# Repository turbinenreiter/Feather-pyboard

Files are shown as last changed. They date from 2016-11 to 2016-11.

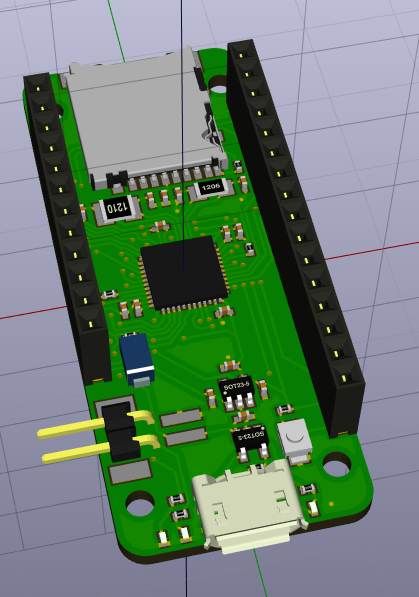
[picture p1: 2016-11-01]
Feather-Pyboard.png

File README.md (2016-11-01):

# Feather-pyboard

A STM32F411 development board compatible with the Feather form factor and designed to run MicroPython.

*NOTE: The desing is as of yet untested.*

This design heavily leans on [Adafruit Feather M0 Adalogger](https://github.com/adafruit/Adafruit-Feather-M0-Adalogger-PCB), [MicroPython pyboard](https://github.com/micropython/pyboard) and [Espruino Pico](https://github.com/espruino/EspruinoBoard/tree/master/Pico).

[Creative Commons Attribution, Share-Alike license](https://creativecommons.org/licenses/by/4.0)

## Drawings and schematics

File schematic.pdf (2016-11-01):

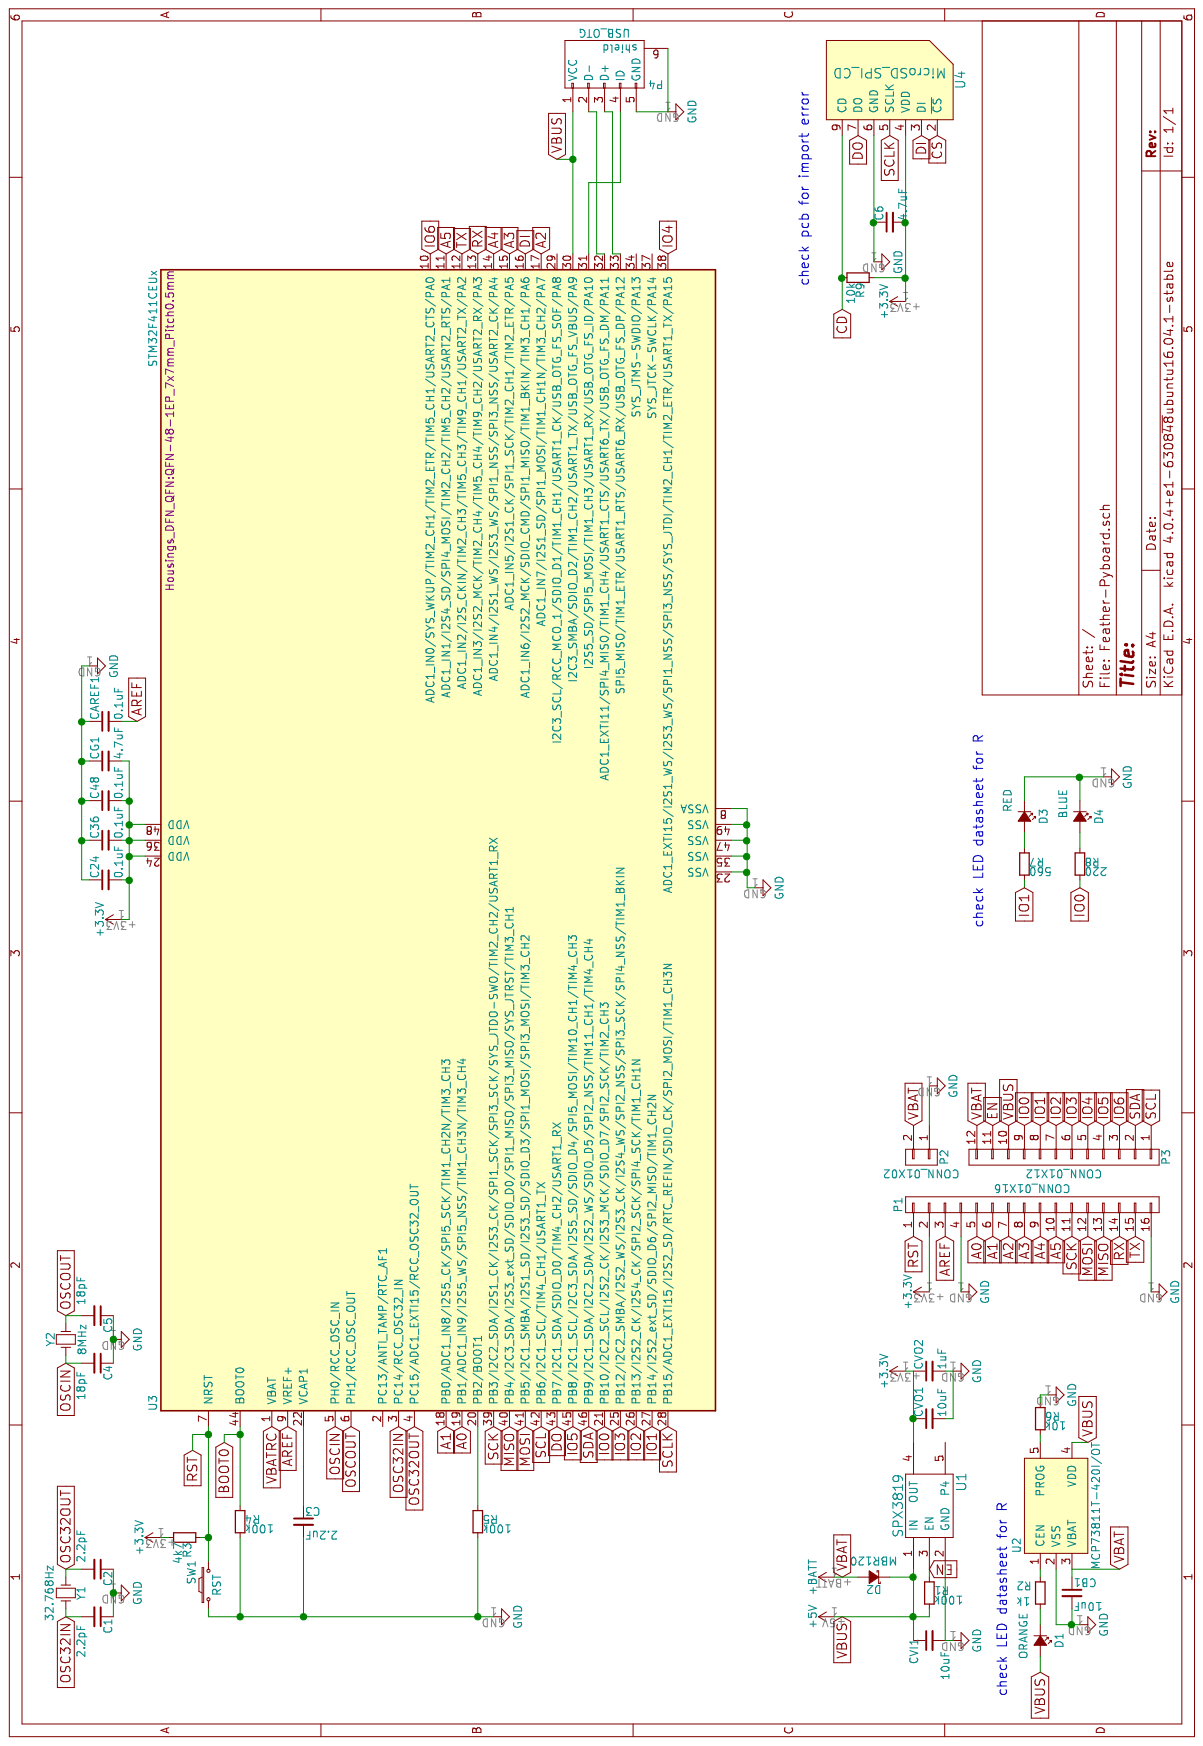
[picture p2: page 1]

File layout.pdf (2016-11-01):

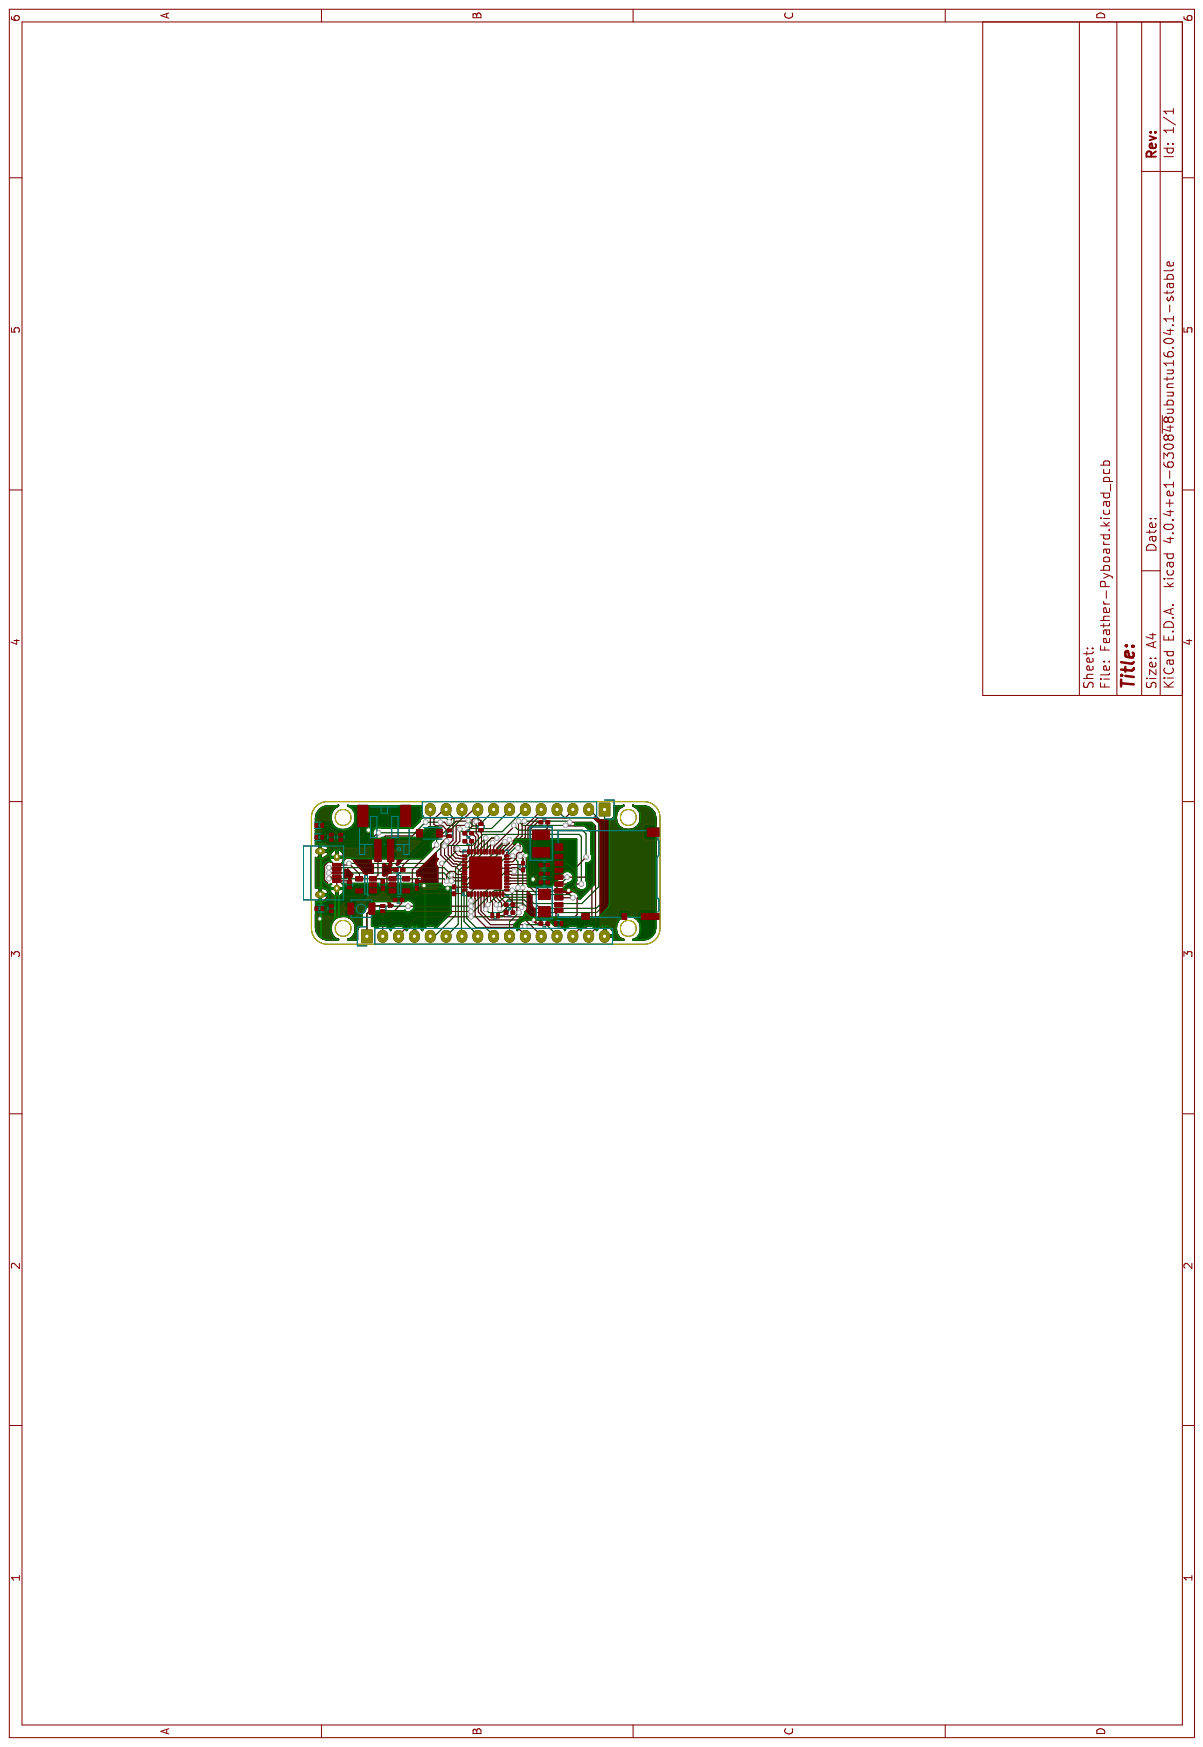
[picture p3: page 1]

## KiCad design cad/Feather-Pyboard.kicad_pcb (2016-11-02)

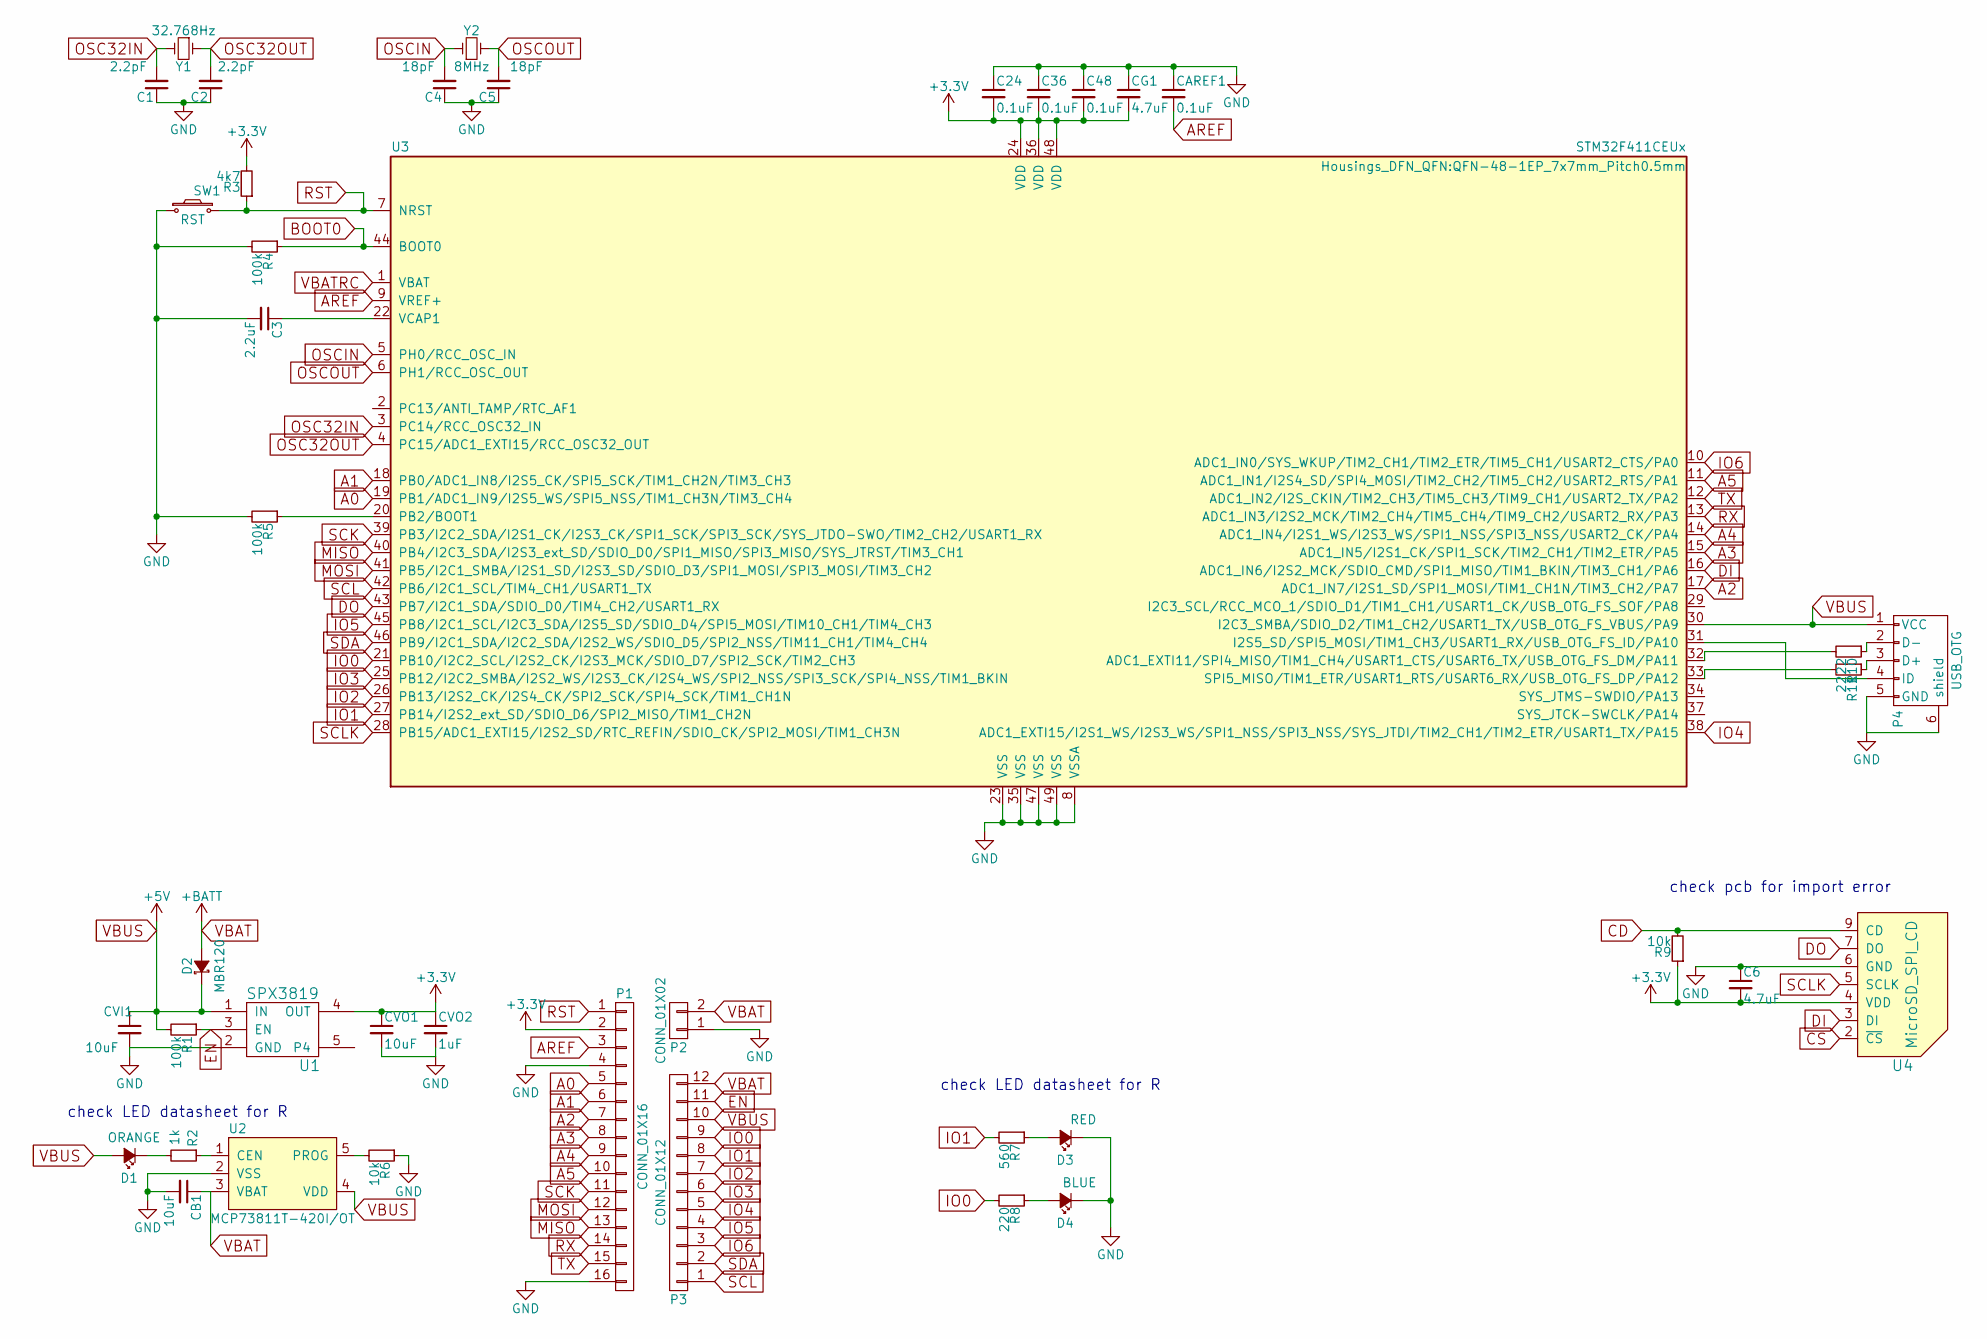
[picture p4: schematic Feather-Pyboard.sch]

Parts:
C1, C2: 2.2pF; C_0402
C3: 2.2uF; C_0402
C4, C5: 18pF; C_0402
C6: 4.7uF; C_0402
C24, C36, C48: 0.1uF; C_0402
CAREF1: 0.1uF; C_0402
CB1: 10uF; C_0402
CG1: 4.7uF; C_0402
CVI1: 10uF; C_0402
CVO1: 10uF; C_0402
CVO2: 1uF; C_0402
D1: ORANGE; LED_0402
D2: MBR120; SOD-123
D3: RED; LED_0402
D4: BLUE; LED_0402
P1: CONN_01X16; Socket_Strip_Straight_1x16
P2: CONN_01X02; JST_PH_S2B-PH-SM4-TB_02x2.00mm_Angled
P3: CONN_01X12; Socket_Strip_Straight_1x12
P4: USB_OTG; USB_Micro-B
R1, R4, R5: 100k; R_0402
R2: 1k; R_0402
R3: 4k7; R_0402
R6, R9: 10k; R_0402
R7: 560; R_0402
R8: 220; R_0402
R10, R11: 22; R_0402
SW1: RST; SW_SPST_B3U-1000P
U1: SPX3819; SOT-23-5
U2: MCP73811T-420I/OT; SOT-23-5
U3: STM32F411CEUx; QFN-48-1EP_7x7mm_Pitch0.5mm
U4: MicroSD_SPI_CD; HIROSE-MICROSD-DM3AT-SF
Y1: 32.768Hz; R-0805
Y2: 8MHz; Crystal_SMD_ABM3B

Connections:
+3V3: C6.2, C24.2, C36.2, C48.2, CG1.2, CVO1.1, CVO2.1, P1.2, R3.2, R9.1, U1.4 (OUT), U3.24 (VDD), U3.36 (VDD), U3.48 (VDD), U4.4 (VDD)
A0: P1.5, U3.19 (PB1/ADC1_IN9/I2S5_WS/SPI5_NSS/TIM1_CH3N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)
A1: P1.6, U3.18 (PB0/ADC1_IN8/I2S5_CK/SPI5_SCK/TIM1_CH2N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)
A2: P1.7, U3.17 (ADC1_IN7/I2S1_SD/SPI1_MOSI/TIM1_CH1N/TI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)
A3: P1.8, U3.15 (ADC1_IN5/I2S1_CK/SPI1_SCK/TIM2_CH1/TIM2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)
A4: P1.9, U3.14 (ADC1_IN4/I2S1_WS/I2S3_WS/SPI1_NSS/SPI3_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)
A5: P1.10, U3.11 (ADC1_IN1/I2S4_SD/SPI4_MOSI/TIM2_CH2/TIM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)
AREF: CAREF1.2, P1.3, U3.9 (VREF+)
BOOT0: R4.1, U3.44 (BOOT0)
CD: R9.2, U4.9 (CD)
CS: U4.2 (~CS)
DI: U3.16 (ADC1_IN6/I2S2_MCK/SDIO_CMD/SPI1_MISO/TI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), U4.3 (DI)
DO: U3.43 (PB7/I2C1_SDA/SDIO_D0/TIM4_CH2/USART1_RX), U4.7 (DO)
EN: P3.11, R1.1, U1.3 (EN)
GND: C1.1, C2.1, C3.2, C4.1, C5.1, C6.1, C24.1, C36.1, C48.1, CAREF1.1, CB1.2, CG1.1, CVI1.2, CVO1.2, CVO2.2, D3.1 (K), D4.1 (K), P1.4, P1.16, P2.1, P4.5 (GND), P4.6 (shield), R4.2, R5.2, R6.1, SW1.1, U1.2 (GND), U2.2 (VSS), U3.8 (VSSA), U3.23 (VSS), U3.35 (VSS), U3.47 (VSS), U3.49 (VSS), U4.6 (GND)
IO0: P3.9, R8.2, U3.21 (PB10/I2C2_SCL/I2S2_CK/I2S3_MCK/SDIO_D7/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)
IO1: P3.8, R7.2, U3.27 (PB14/I2S2_ext_SD/SDIO_D6/SPI2_MISO/TIM1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)
IO2: P3.7, U3.26 (PB13/I2S2_CK/I2S4_CK/SPI2_SCK/SPI4_SCK/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)
IO3: P3.6, U3.25 (PB12/I2C2_SMBA/I2S2_WS/I2S3_CK/I2S4_WS/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)
IO4: P3.5, U3.38 (ADC1_EXTI15/I2S1_WS/I2S3_WS/SPI1_NSS/SP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)
IO5: P3.4, U3.45 (PB8/I2C1_SCL/I2C3_SDA/I2S5_SD/SDIO_D4/S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)
IO6: P3.3, U3.10 (ADC1_IN0/SYS_WKUP/TIM2_CH1/TIM2_ETR/TIM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)
MISO: P1.13, U3.40 (PB4/I2C3_SDA/I2S3_ext_SD/SDIO_D0/SPI1_M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)
MOSI: P1.12, U3.41 (PB5/I2C1_SMBA/I2S1_SD/I2S3_SD/SDIO_D3/S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)
unnamed: C3.1, U3.22 (VCAP1)
unnamed: D1.1 (K), R2.2
unnamed: D3.2 (A), R7.1
unnamed: D4.2 (A), R8.1
unnamed: P4.2 (D-), R10.1
unnamed: P4.3 (D+), R11.1
unnamed: P4.4 (ID), U3.31 (I2S5_SD/SPI5_MOSI/TIM1_CH3/USART1_RX/US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)
unnamed: R2.1, U2.1 (CEN)
unnamed: R5.1, U3.20 (PB2/BOOT1)
unnamed: R6.2, U2.5 (PROG)
unnamed: R10.2, U3.32 (ADC1_EXTI11/SPI4_MISO/TIM1_CH4/USART1_C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)
unnamed: R11.2, U3.33 (SPI5_MISO/TIM1_ETR/USART1_RTS/USART6_RX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)
OSC32IN: C1.2, U3.3 (PC14/RCC_OSC32_IN), Y1.2
OSC32OUT: C2.2, U3.4 (PC15/ADC1_EXTI15/RCC_OSC32_OUT), Y1.1
OSCIN: C4.2, U3.5 (PH0/RCC_OSC_IN), Y2.1
OSCOUT: C5.2, U3.6 (PH1/RCC_OSC_OUT), Y2.2
RST: P1.1, R3.1, SW1.2, U3.7 (NRST)
RX: P1.14, U3.13 (ADC1_IN3/I2S2_MCK/TIM2_CH4/TIM5_CH4/TIM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)
SCK: P1.11, U3.39 (PB3/I2C2_SDA/I2S1_CK/I2S3_CK/SPI1_SCK/S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)
SCL: P3.1, U3.42 (PB6/I2C1_SCL/TIM4_CH1/USART1_TX)
SCLK: U3.28 (PB15/ADC1_EXTI15/I2S2_SD/RTC_REFIN/SDIO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), U4.5 (SCLK)
SDA: P3.2, U3.46 (PB9/I2C1_SDA/I2C2_SDA/I2S2_WS/SDIO_D5/S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)
TX: P1.15, U3.12 (ADC1_IN2/I2S_CKIN/TIM2_CH3/TIM5_CH3/TIM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)
VBAT: CB1.1, D2.2 (A), P2.2, P3.12, U2.3 (VBAT)
VBATRC: U3.1 (VBAT)
VBUS: CVI1.1, D1.2 (A), D2.1 (K), P3.10, P4.1 (VCC), R1.2, U1.1 (IN), U2.4 (VDD), U3.30 (I2C3_SMBA/SDIO_D2/TIM1_CH2/USART1_TX/US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)

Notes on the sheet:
check LED datasheet for R
check pcb for import error

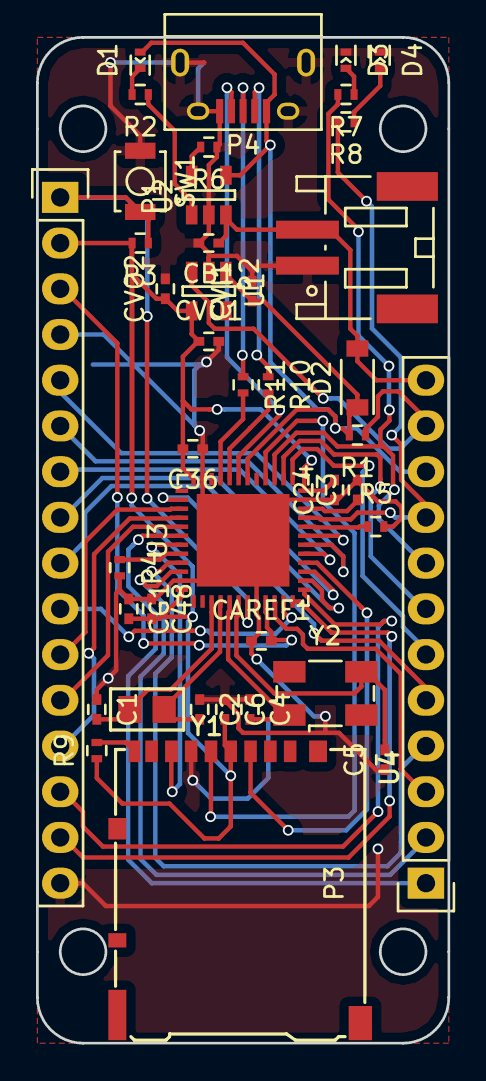
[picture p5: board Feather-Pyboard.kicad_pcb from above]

Board: 2 copper layers, 22.9 x 55.9 mm, 41 parts (0 on the bottom side), 48 nets.

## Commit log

2016-11-01 initial commit for review
    [Feather-Pyboard.kicad_pcb, Feather-Pyboard.sch]
2016-11-02 new crystal footrpints and 22 ohm resistors for usb
    [Feather-Pyboard.kicad_pcb, Feather-Pyboard.sch]
